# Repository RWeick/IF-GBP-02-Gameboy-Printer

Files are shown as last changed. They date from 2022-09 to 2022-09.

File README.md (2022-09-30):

# IF-GBP-02-Gameboy-Printer
The full schematic and gerbers for the Nintendo Gameboy Printer PCB revision 02

This schematic is verified to be 100% complete and accurate.

PCB Thickness: 1.2 mm

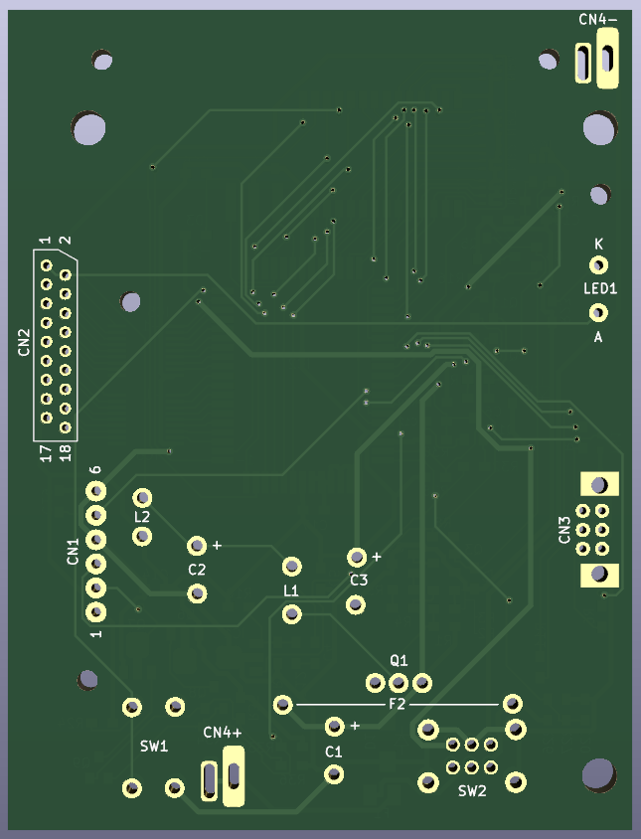
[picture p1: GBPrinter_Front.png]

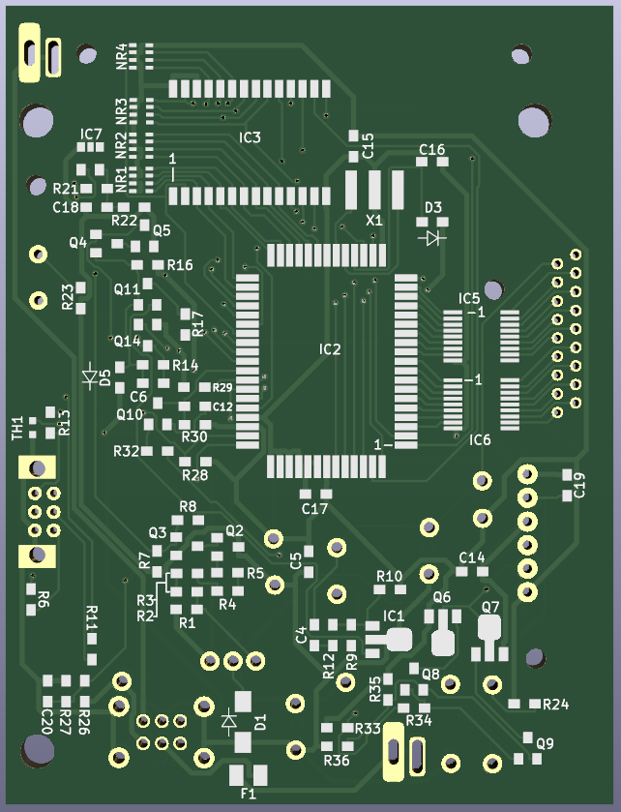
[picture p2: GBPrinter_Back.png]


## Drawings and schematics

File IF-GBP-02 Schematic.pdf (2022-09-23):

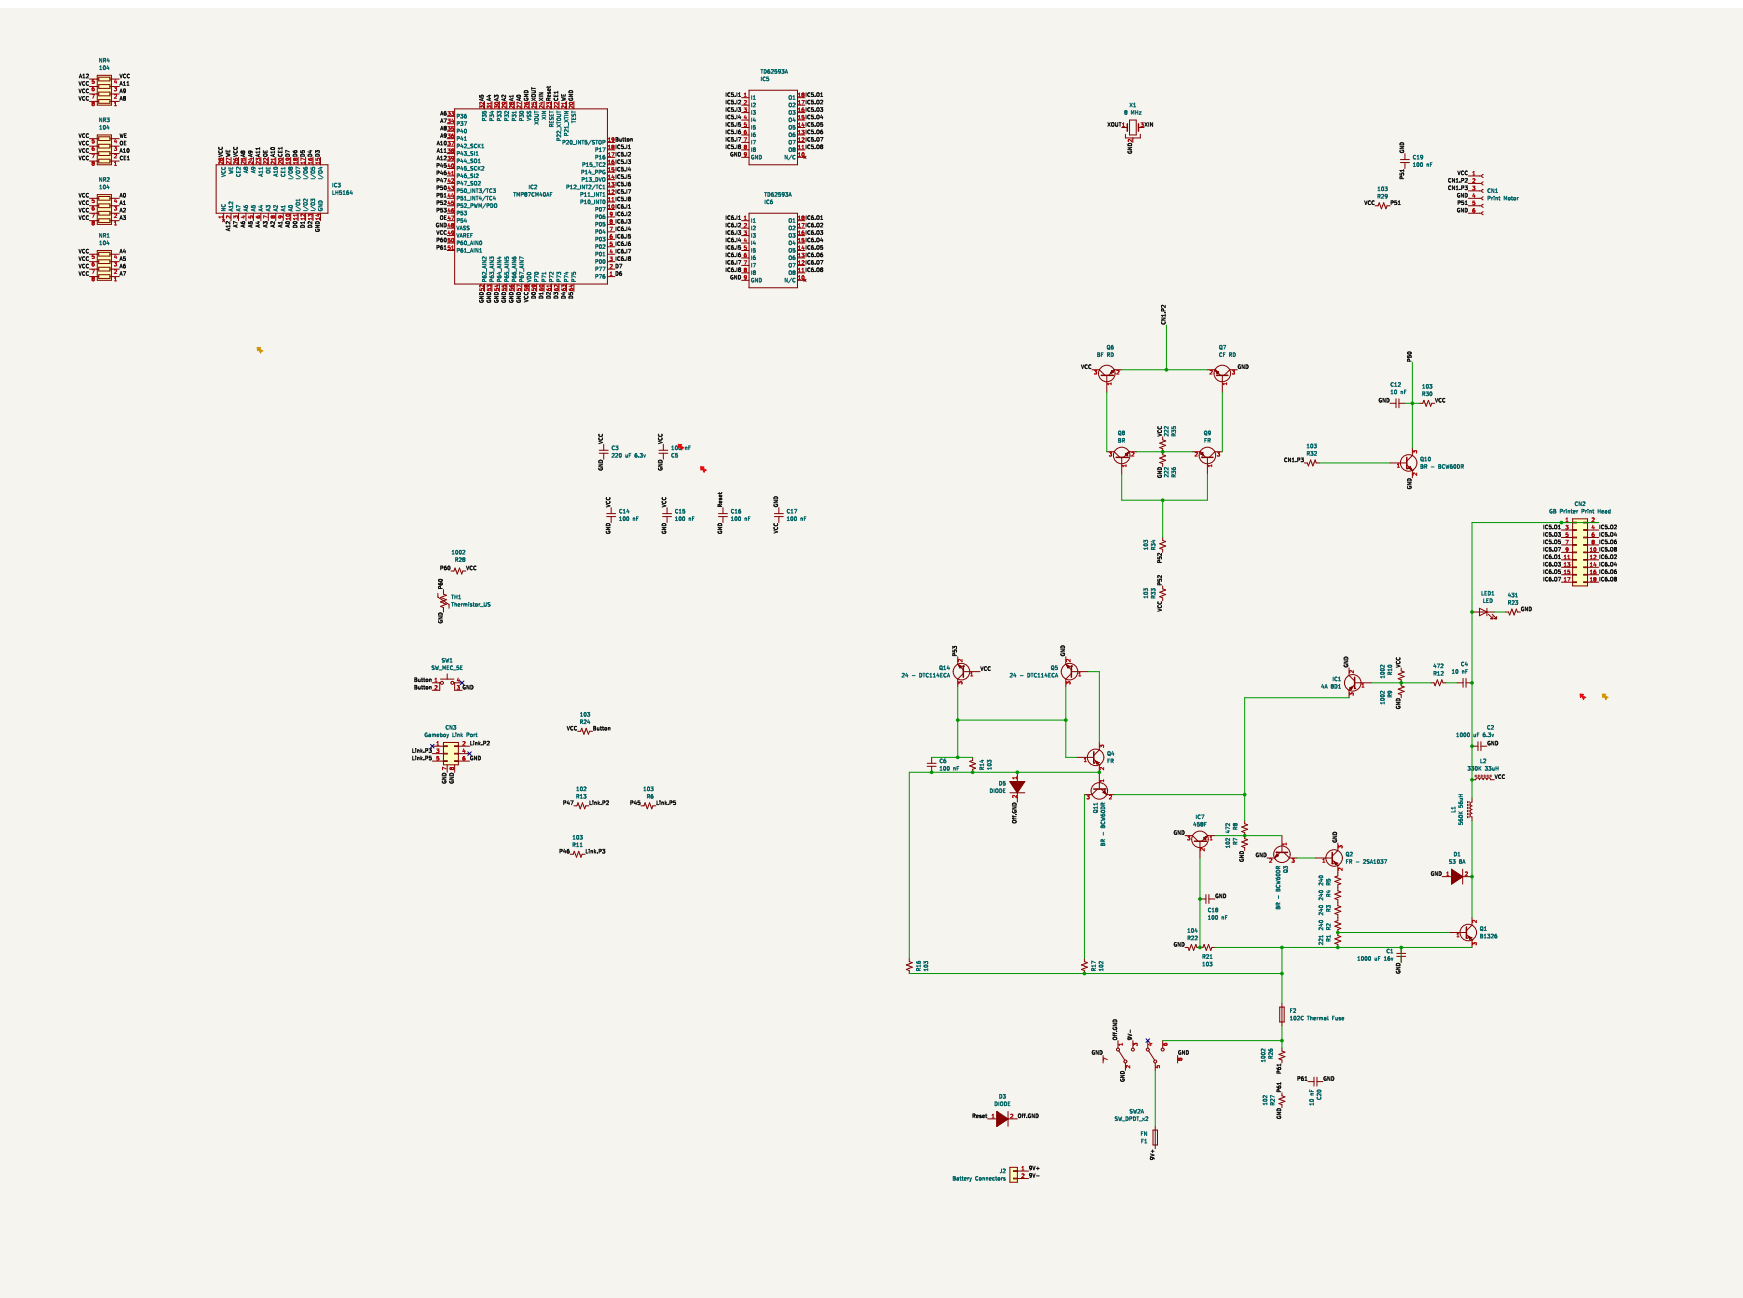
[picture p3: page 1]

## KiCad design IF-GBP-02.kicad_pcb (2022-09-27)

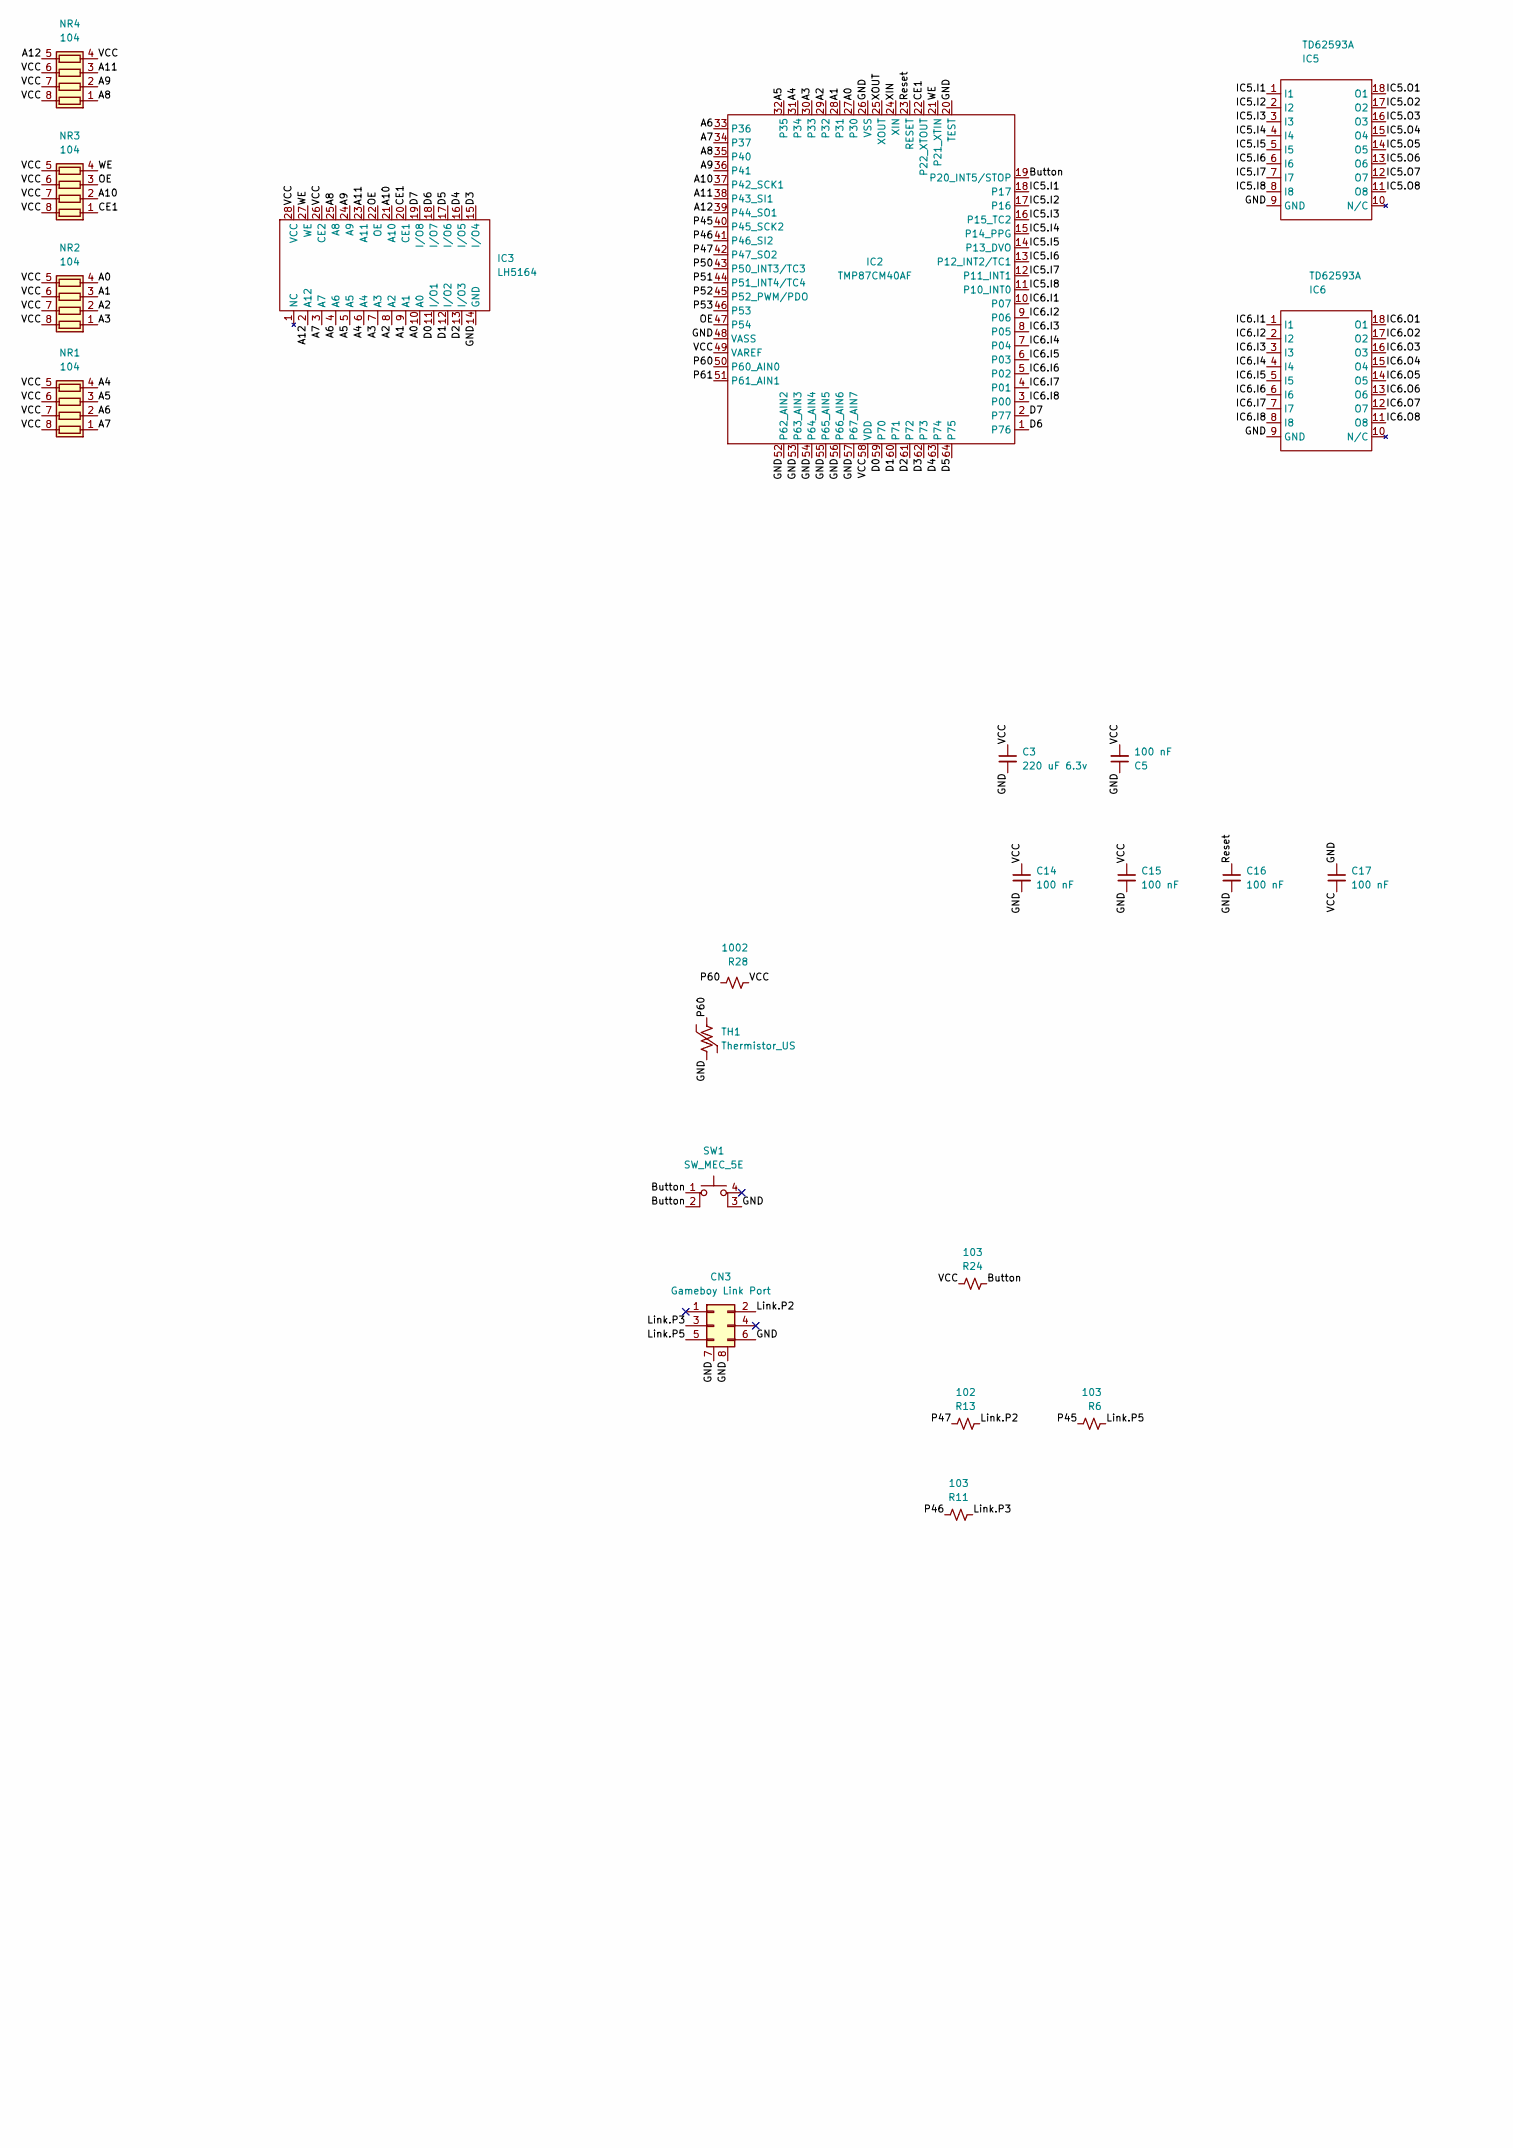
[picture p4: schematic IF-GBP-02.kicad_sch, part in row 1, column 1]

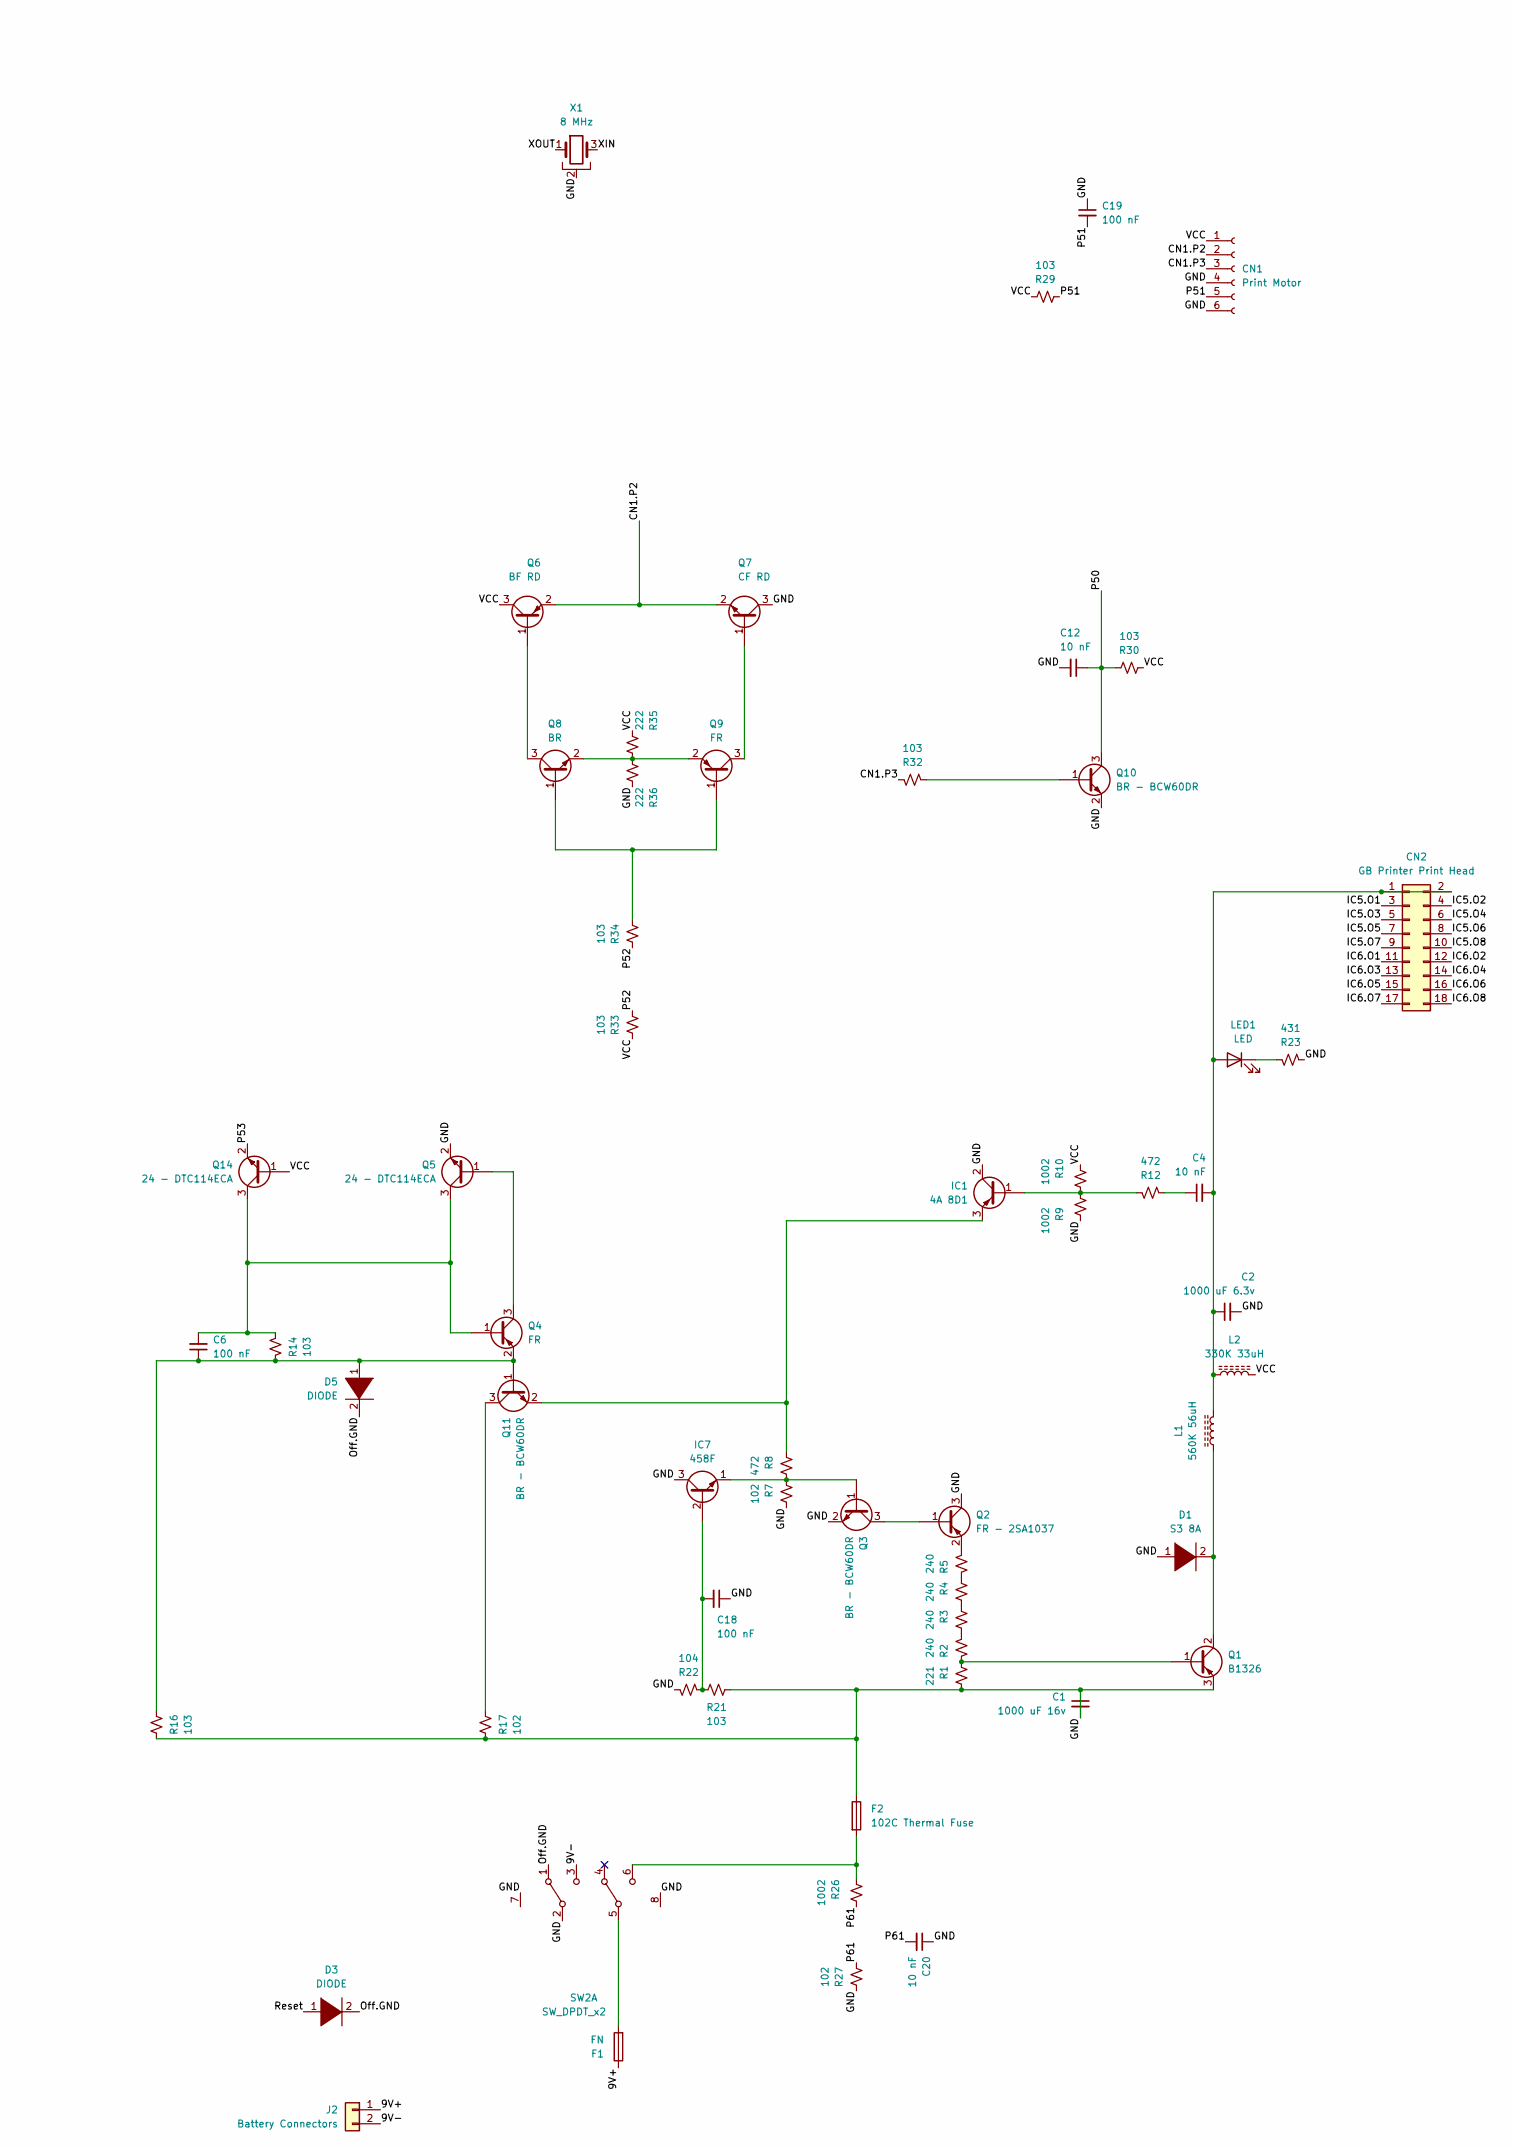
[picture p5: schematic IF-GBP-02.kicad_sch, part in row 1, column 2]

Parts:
C1: 1000 uF 16v; C1 1000 uF Cap
C2: 1000 uF 6.3v; C2 1000 uF Cap
C3: 220 uF 6.3v; C3 220 uF Cap
C4, C12, C20: 10 nF; SMD Cap-Res
C5, C6, C14, C15, C16, C17, C18, C19: 100 nF; SMD Cap-Res
CN1: Print Motor; Printer Motor Connector
CN2: GB Printer Print Head; Printer Head Connector
CN3: Gameboy Link Port
D1: S3 8A; D1 Diode
D3, D5: DIODE; Little Diode
F1: FN; F1 Fuse
F2: 102C Thermal Fuse; F2 Thermal Fuse
IC1: 4A 8D1; SOT89 Transistor
IC2: TMP87CM40AF
IC3: LH5164; LH5164 SRAM
IC5, IC6: TD62593A
IC7: 458F; SOT23-5 Transistor
J2: Battery Connectors
L1: 560K 56uH; L1 Inductor
L2: 330K 33uH; L2 Inductor
LED1: LED
NR1, NR2, NR3, NR4: 104; Resistor Pack
Q1: B1326
Q2: FR - 2SA1037; Transistor
Q3, Q10, Q11: BR - BCW60DR; Transistor
Q4, Q9: FR; Transistor
Q5, Q14: 24 - DTC114ECA; Transistor
Q6: BF RD; SOT89 Transistor
Q7: CF RD; SOT89 Transistor
Q8: BR; Transistor
R1: 221; SMD Cap-Res
R2, R3, R4, R5: 240; SMD Cap-Res
R6, R11, R14, R16, R21, R24, R29, R30, R32, R33, R34: 103; SMD Cap-Res
R7, R13, R17, R27: 102; SMD Cap-Res
R8, R12: 472; SMD Cap-Res
R9, R10, R26, R28: 1002; SMD Cap-Res
R22: 104; SMD Cap-Res
R23: 431; SMD Cap-Res
R35, R36: 222; SMD Cap-Res
SW1: SW_MEC_5E; Feed Button
SW2: SW_DPDT_x2; Slide Switch
TH1: Thermistor_US; TH1 Thermistor
X1: 8 MHz; 8 MHz Crystal

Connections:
/9V+: F1.1, J2.1
/9V-: J2.2, SW2.3 (C)
/9V.F1: F1.2, SW2.5 (B)
/9V.Prefuse: F2.2, R26.2, SW2.6 (C)
/A0: IC2.27 (P30), IC3.10 (A0), NR2.4 (R4.1)
/A1: IC2.28 (P31), IC3.9 (A1), NR2.3 (R3.1)
/A2: IC2.29 (P32), IC3.8 (A2), NR2.2 (R2.1)
/A3: IC2.30 (P33), IC3.7 (A3), NR2.1 (R1.1)
/A4: IC2.31 (P34), IC3.6 (A4), NR1.4 (R4.1)
/A5: IC2.32 (P35), IC3.5 (A5), NR1.3 (R3.1)
/A6: IC2.33 (P36), IC3.4 (A6), NR1.2 (R2.1)
/A7: IC2.34 (P37), IC3.3 (A7), NR1.1 (R1.1)
/A8: IC2.35 (P40), IC3.25 (A8), NR4.1 (R1.1)
/A9: IC2.36 (P41), IC3.24 (A9), NR4.2 (R2.1)
/A10: IC2.37 (P42_SCK1), IC3.21 (A10), NR3.2 (R2.1)
/A11: IC2.38 (P43_SI1), IC3.23 (A11), NR4.3 (R3.1)
/A12: IC2.39 (P44_SO1), IC3.2 (A12), NR4.5 (R4.2)
/Button: IC2.19 (P20_INT5/STOP), R24.2, SW1.1, SW1.2
/CE1: IC2.22 (P22_XTOUT), IC3.20 (CE1), NR3.1 (R1.1)
/CN1.P2: CN1.2, Q6.2 (VIN), Q7.2 (E)
/CN1.P3: CN1.3, R32.2
/D0: IC2.59 (P70), IC3.11 (I/O1)
/D1: IC2.60 (P71), IC3.12 (I/O2)
/D2: IC2.61 (P72), IC3.13 (I/O3)
/D3: IC2.62 (P73), IC3.15 (I/O4)
/D4: IC2.63 (P74), IC3.16 (I/O5)
/D5: IC2.64 (P75), IC3.17 (I/O6)
/D6: IC2.1 (P76), IC3.18 (I/O7)
/D7: IC2.2 (P77), IC3.19 (I/O8)
/IC5.I1: IC2.18 (P17), IC5.1 (I1)
/IC5.I2: IC2.17 (P16), IC5.2 (I2)
/IC5.I3: IC2.16 (P15_TC2), IC5.3 (I3)
/IC5.I4: IC2.15 (P14_PPG), IC5.4 (I4)
/IC5.I5: IC2.14 (P13_DVO), IC5.5 (I5)
/IC5.I6: IC2.13 (P12_INT2/TC1), IC5.6 (I6)
/IC5.I7: IC2.12 (P11_INT1), IC5.7 (I7)
/IC5.I8: IC2.11 (P10_INT0), IC5.8 (I8)
/IC5.O1: CN2.3, IC5.18 (O1)
/IC5.O2: CN2.4, IC5.17 (O2)
/IC5.O3: CN2.5, IC5.16 (O3)
/IC5.O4: CN2.6, IC5.15 (O4)
/IC5.O5: CN2.7, IC5.14 (O5)
/IC5.O6: CN2.8, IC5.13 (O6)
/IC5.O7: CN2.9, IC5.12 (O7)
/IC5.O8: CN2.10, IC5.11 (O8)
/IC6.I1: IC2.10 (P07), IC6.1 (I1)
/IC6.I2: IC2.9 (P06), IC6.2 (I2)
/IC6.I3: IC2.8 (P05), IC6.3 (I3)
/IC6.I4: IC2.7 (P04), IC6.4 (I4)
/IC6.I5: IC2.6 (P03), IC6.5 (I5)
/IC6.I6: IC2.5 (P02), IC6.6 (I6)
/IC6.I7: IC2.4 (P01), IC6.7 (I7)
/IC6.I8: IC2.3 (P00), IC6.8 (I8)
/IC6.O1: CN2.11, IC6.18 (O1)
/IC6.O2: CN2.12, IC6.17 (O2)
/IC6.O3: CN2.13, IC6.16 (O3)
/IC6.O4: CN2.14, IC6.15 (O4)
/IC6.O5: CN2.15, IC6.14 (O5)
/IC6.O6: CN2.16, IC6.13 (O6)
/IC6.O7: CN2.17, IC6.12 (O7)
/IC6.O8: CN2.18, IC6.11 (O8)
/LED.Anode: C2.1, C4.2, CN2.1, CN2.2, L1.1, L2.1, LED1.2 (A)
/LED.Cathode: LED1.1 (K), R23.2
/Link.P2: CN3.2, R13.2
/Link.P3: CN3.3, R11.2
/Link.P5: CN3.5, R6.2
/OE: IC2.47 (P54), IC3.22 (OE), NR3.3 (R3.1)
/Off.GND: D3.2 (A), D5.2 (A), SW2.1 (A)
/P45: IC2.40 (P45_SCK2), R6.1
/P46: IC2.41 (P46_SI2), R11.1
/P47: IC2.42 (P47_SO2), R13.1
/P50: C12.1, IC2.43 (P50_INT3/TC3), Q10.3 (C), R30.1
/P51: C19.2, CN1.5, IC2.44 (P51_INT4/TC4), R29.2
/P52: IC2.45 (P52_PWM/PDO), R33.2, R34.1
/P53: IC2.46 (P53), Q14.2 (E)
/P60: IC2.50 (P60_AIN0), R28.1, TH1.1
/P61: C20.2, IC2.51 (P61_AIN1), R26.1, R27.2
/Reset: C16.1, D3.1 (K), IC2.23 (RESET)
/Route1: D1.2 (A), L1.2, Q1.2 (C)
/Route2: Q1.1 (B), R1.2, R2.2
/Route3: R2.1, R3.1
/Route4: R3.2, R4.1
/Route5: R4.2, R5.2
/Route6: Q2.2 (E), R5.1
/Route7: Q2.1 (B), Q3.3 (C)
/Route8: IC1.1 (B), R9.2, R10.1, R12.2
/Route9: C4.1, R12.1
/Route12: Q7.1 (B), Q9.3 (C)
/Route13: Q8.1 (B), Q9.1 (B), R34.2
/Route14: Q8.2 (E), Q9.2 (E), R35.1, R36.2
/Route15: IC1.3 (+), Q11.2 (E), R8.2
/Route16: Q6.1 (GND), Q8.3 (C)
/Route19: C6.1, D5.1 (K), Q4.2 (E), Q11.1 (B), R14.1, R16.1
/Route20: IC7.1 (E), Q3.1 (B), R7.2, R8.1
/Route21: C18.2, IC7.2 (B), R21.2, R22.1
/Route23: C6.2, Q4.1 (B), Q5.3 (C), Q14.3 (C), R14.2
/Route24: Q4.3 (C), Q5.1 (B)
/Route25: Q11.3 (C), R17.1
/Route27: Q10.1 (B), R32.1
/VCC: C3.1, C5.2, C14.1, C15.1, C17.2, CN1.1, IC2.49 (VAREF), IC2.58 (VDD), IC3.26 (CE2), IC3.28 (VCC), L2.2, NR1.5 (R4.2), NR1.6 (R3.2), NR1.7 (R2.2), NR1.8 (R1.2), NR2.5 (R4.2), NR2.6 (R3.2), NR2.7 (R2.2), NR2.8 (R1.2), NR3.5 (R4.2), NR3.6 (R3.2), NR3.7 (R2.2), NR3.8 (R1.2), NR4.4 (R4.1), NR4.6 (R3.2), NR4.7 (R2.2), NR4.8 (R1.2), Q6.3 (VOUT), Q14.1 (B), R10.2, R24.1, R28.2, R29.1, R30.2, R33.1, R35.2
/WE: IC2.21 (P21_XTIN), IC3.27 (WE), NR3.4 (R4.1)
/XIN: IC2.24 (XIN), X1.3
/XOUT: IC2.25 (XOUT), X1.1

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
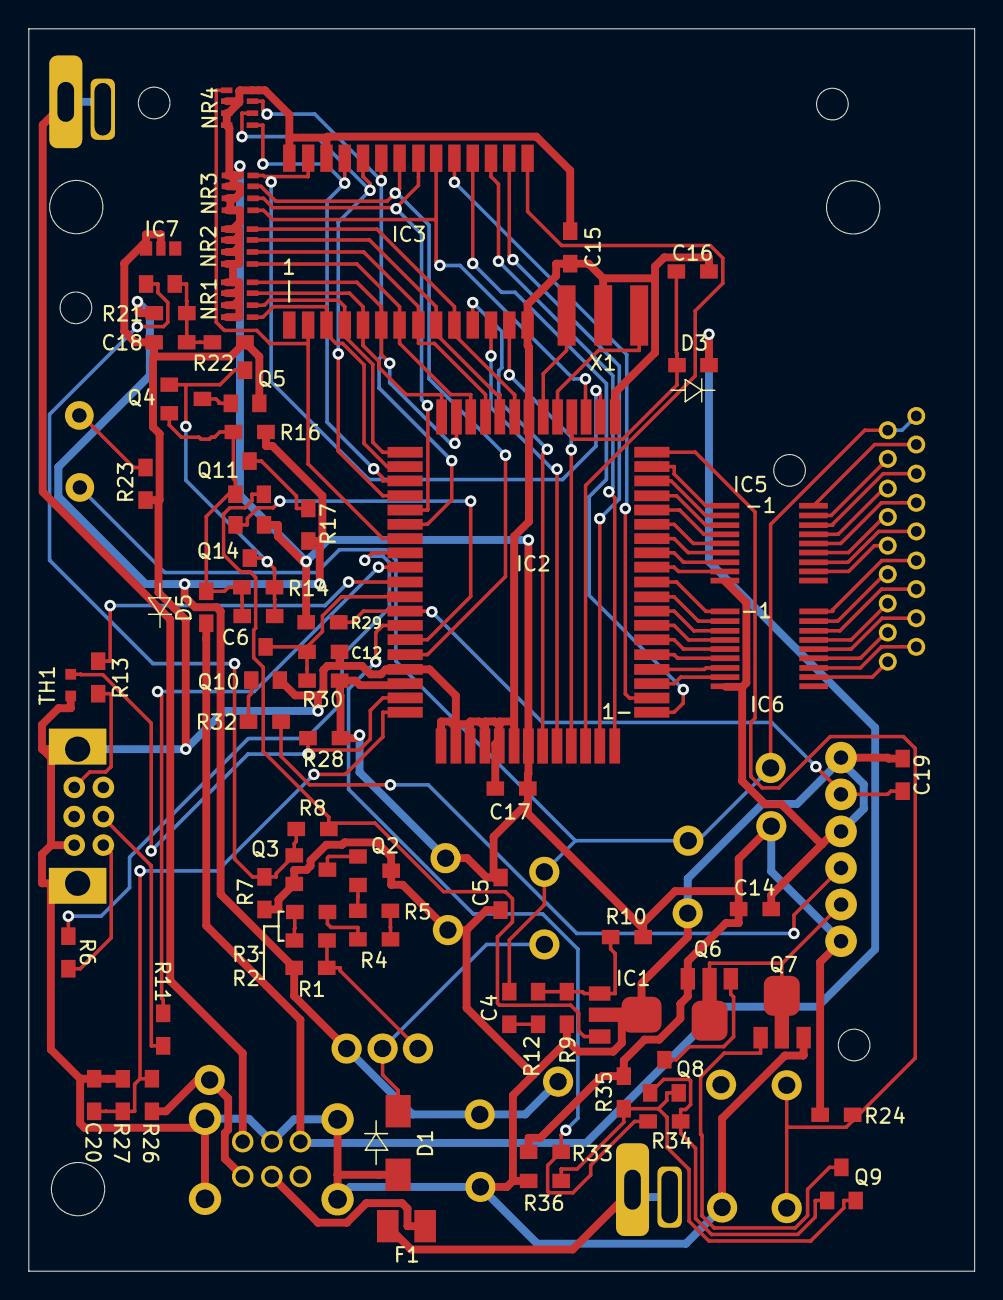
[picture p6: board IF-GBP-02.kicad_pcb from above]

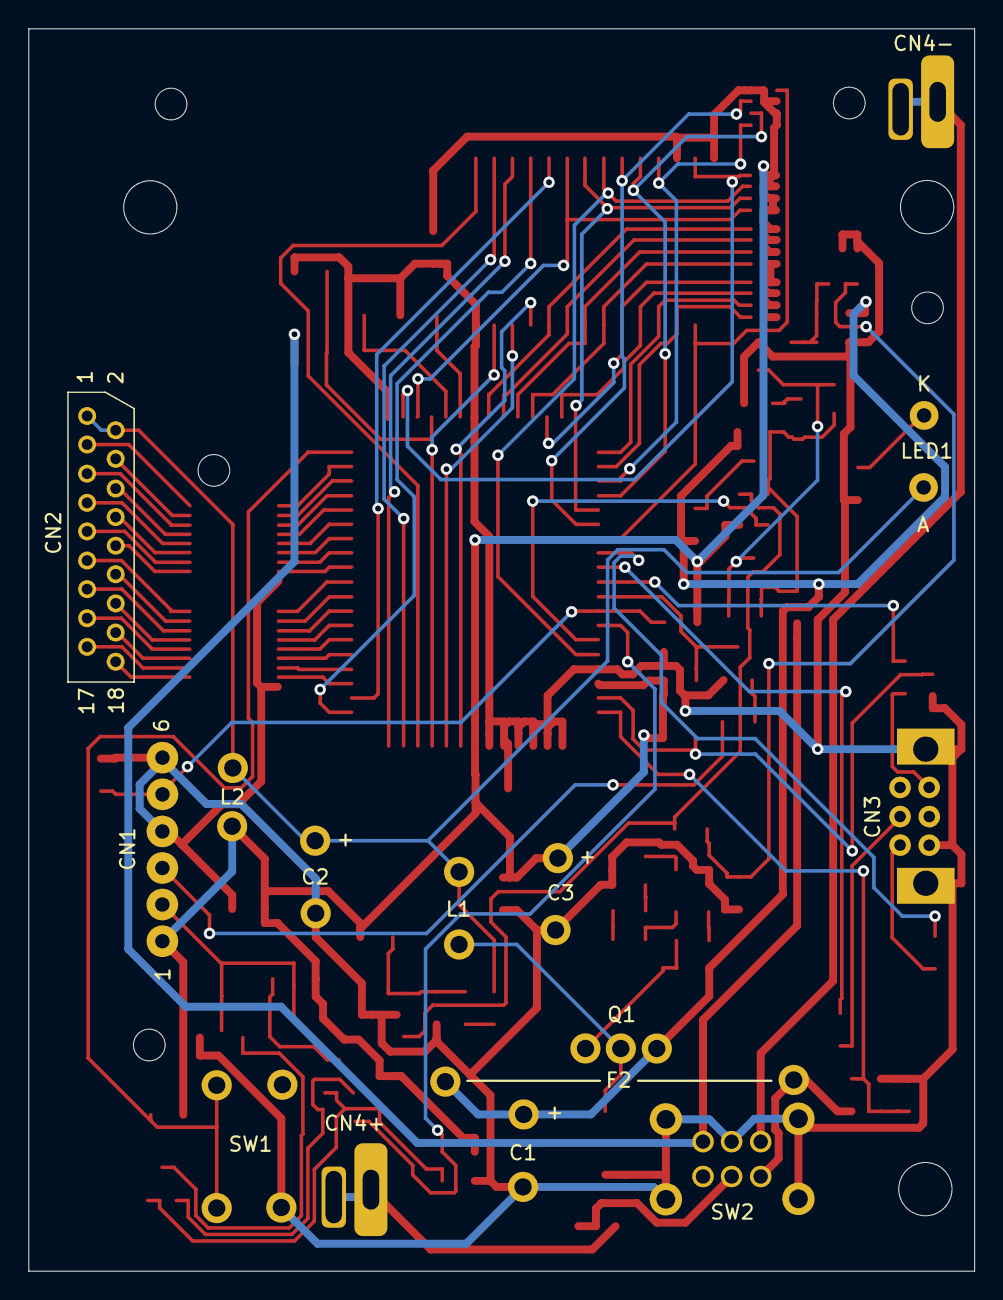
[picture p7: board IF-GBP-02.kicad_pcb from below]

Board: 2 copper layers, 65.7 x 86.3 mm, 93 parts (21 on the bottom side), 105 nets.

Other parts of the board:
D1Diagram, D3Diagram, D5Diagram: 867ee1a9-3078-458d-9784-2b6d66f4ccf8
Hole1, Hole5, Hole7: MountingHole_2.2mm_M2_ISO7380
Hole2, Hole4, Hole6: MountingHole_3.7mm
Hole3, Hole8: MountingHole_2.2mm_M2
